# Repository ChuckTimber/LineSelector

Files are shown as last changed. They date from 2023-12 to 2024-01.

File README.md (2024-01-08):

# LineSelector

[ラインセレクタ - DIY Fx and Synthesizer](https://scrapbox.io/diyfx/%E3%83%A9%E3%82%A4%E3%83%B3%E3%82%BB%E3%83%AC%E3%82%AF%E3%82%BF)

## 仕様
- 基本仕様は A-B-Thru
- I/O は，Input / Output / SendA-ReturnA / SendB-ReturnB / TunerOut
- ２ボタン（A/B切替ボタン と Thru/FX切替ボタン）コントロール
- A/B切り替えボタンで SendA-ReturnA / SendB-ReturnB を切り替え
- Thru/FX ボタン長押しで Tunerモード（本線系はミュートしてチューナにのみ信号を流す）．Thru/FXボタンかA/Bボタンで復帰．
- なお切り替え制御はワンチップマイコン使用

## 回路図

- [version 1.0](Line_Selector_v1p0.pdf) 一部間違いあり，基板パターンを改修した上で動作実績あり
- [version 1.1](Line_Selector_v1p1.pdf) v.1.1を修正したもの．ただし基板は製作しておらず未検証

## 基板修正図

- [Patch 1.0 to 1.1](Patch_v1p0_to_v1p1.pdf) verion 1.0 の基板に対するパッチ情報（基板カットとジャンパ線）

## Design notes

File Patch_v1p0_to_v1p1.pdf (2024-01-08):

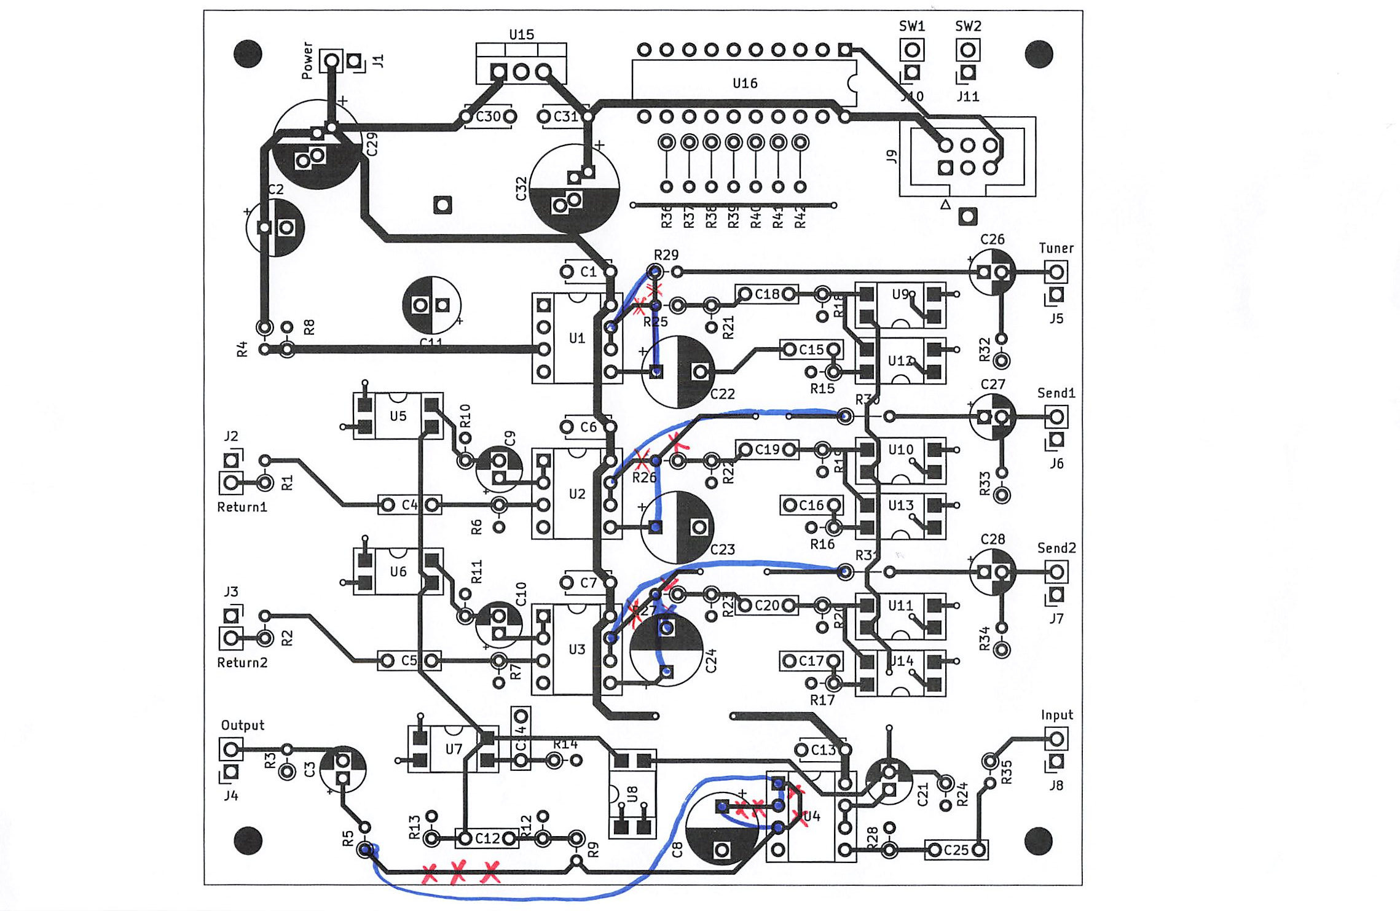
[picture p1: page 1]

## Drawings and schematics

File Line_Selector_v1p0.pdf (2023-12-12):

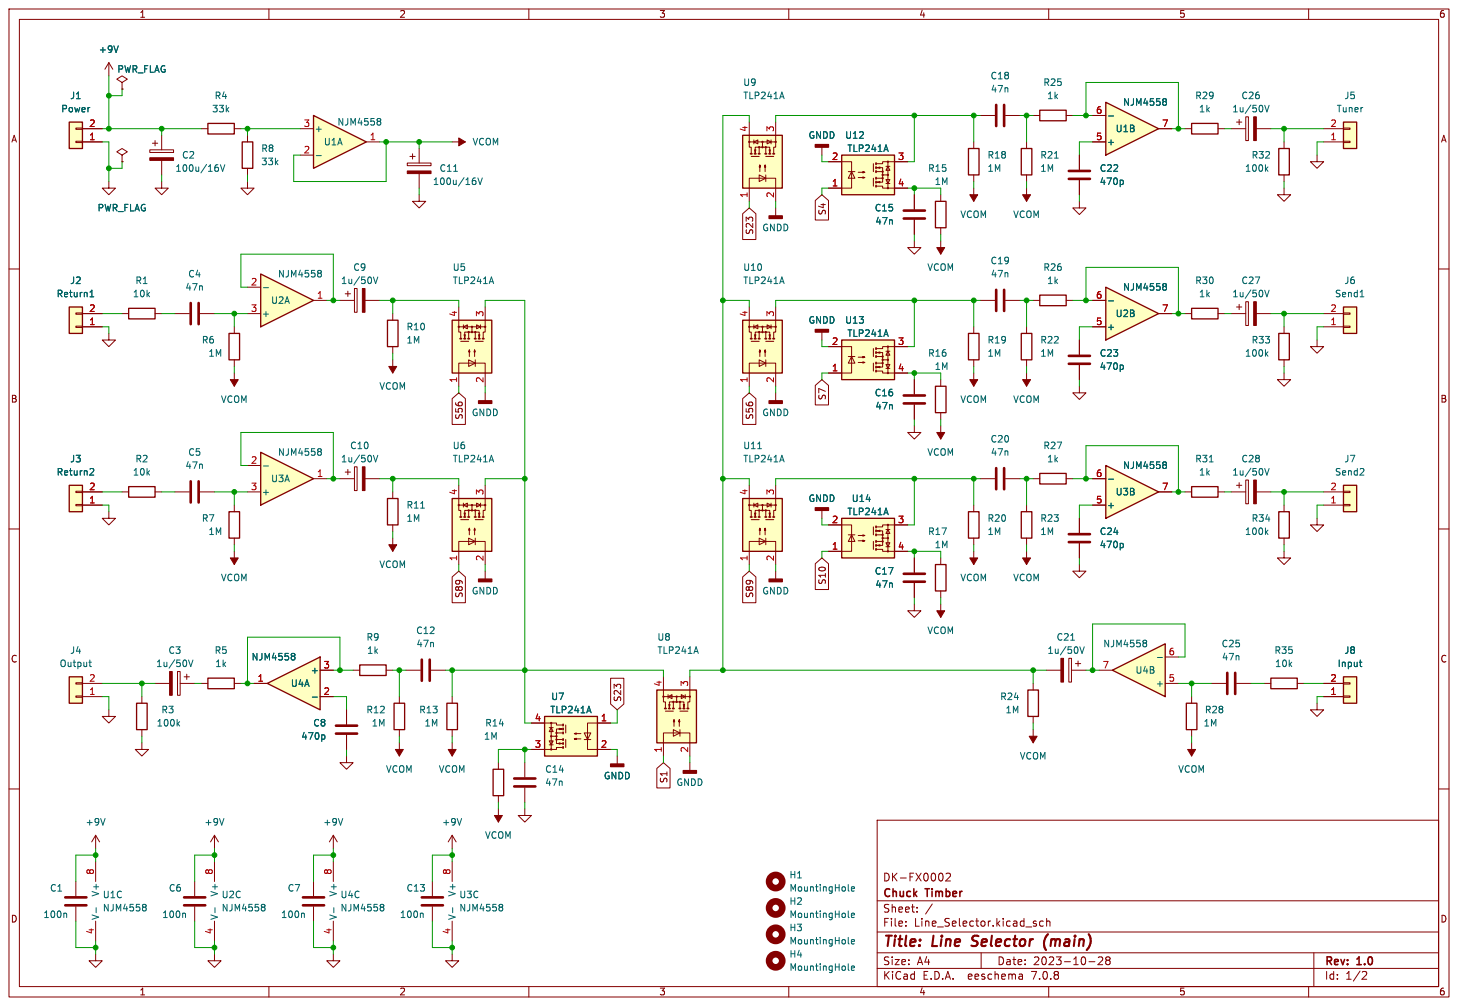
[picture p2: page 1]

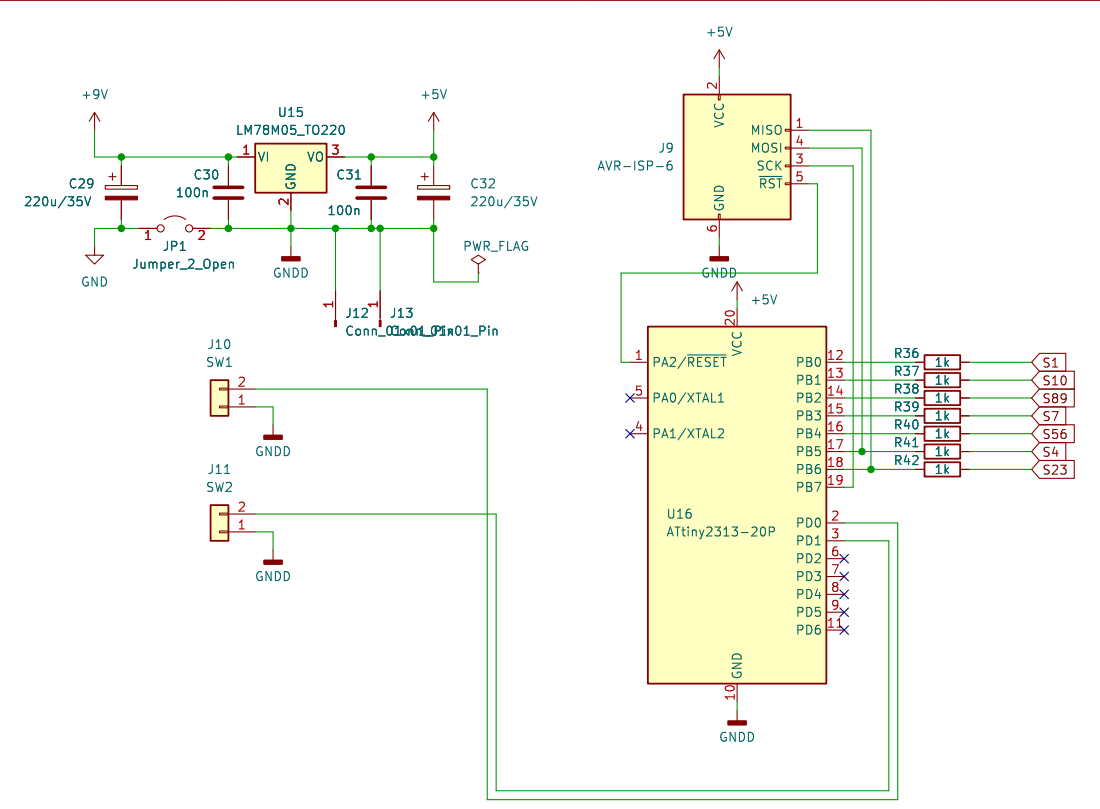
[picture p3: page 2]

2 SCK 3 MOSI 4 ~{RST}5 GND

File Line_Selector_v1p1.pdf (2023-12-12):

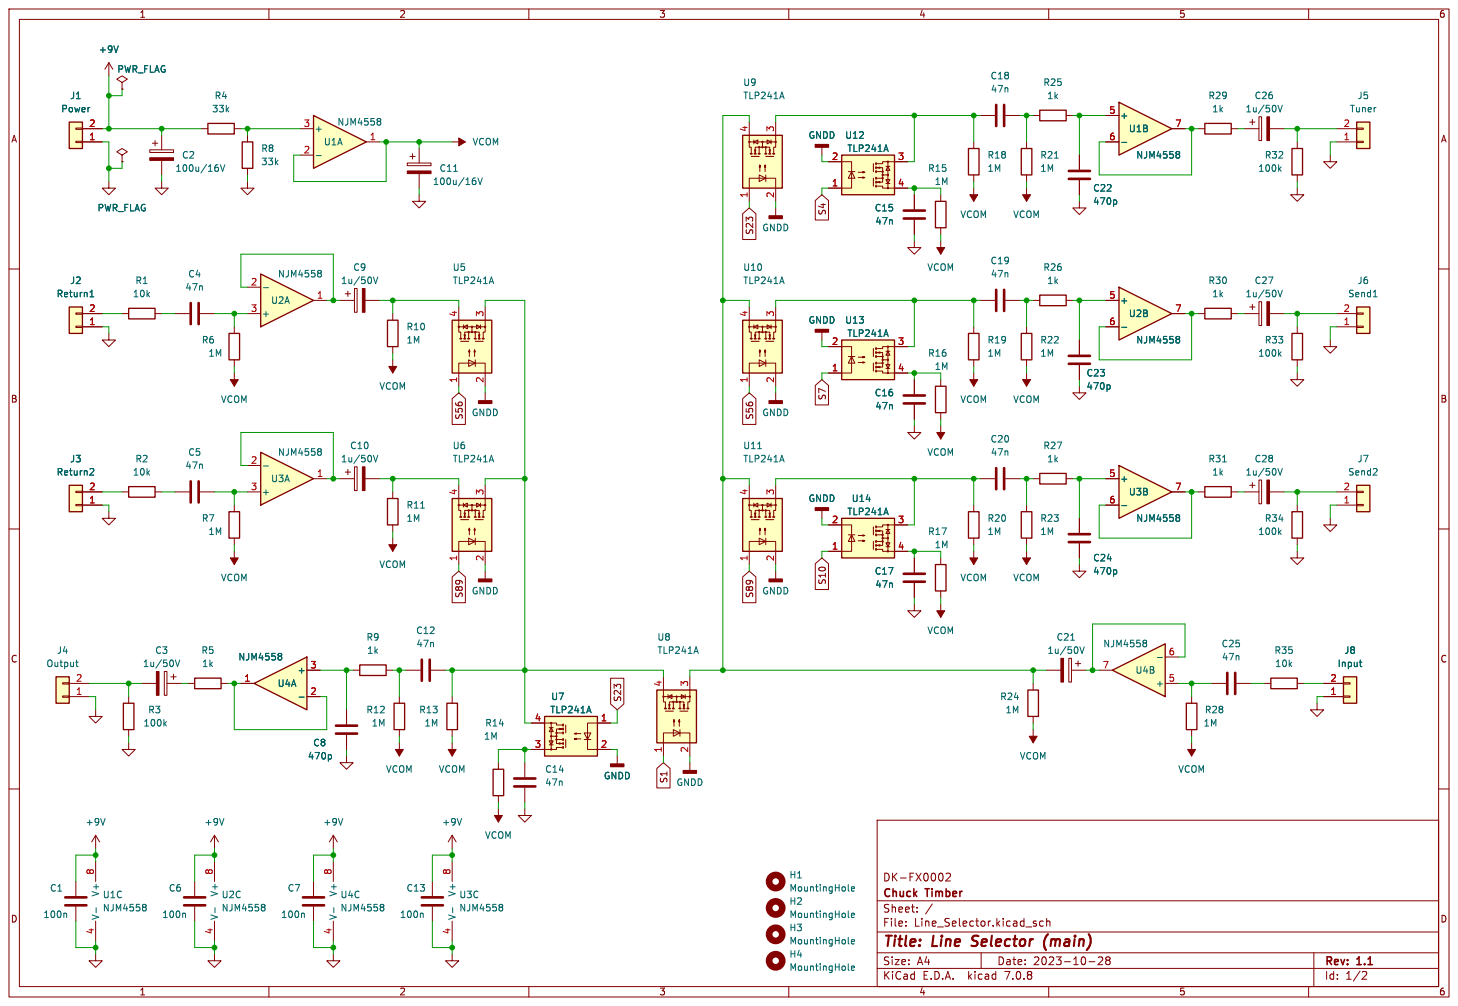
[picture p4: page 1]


2 SCK 3 MOSI 4 ~{RST}5 GND

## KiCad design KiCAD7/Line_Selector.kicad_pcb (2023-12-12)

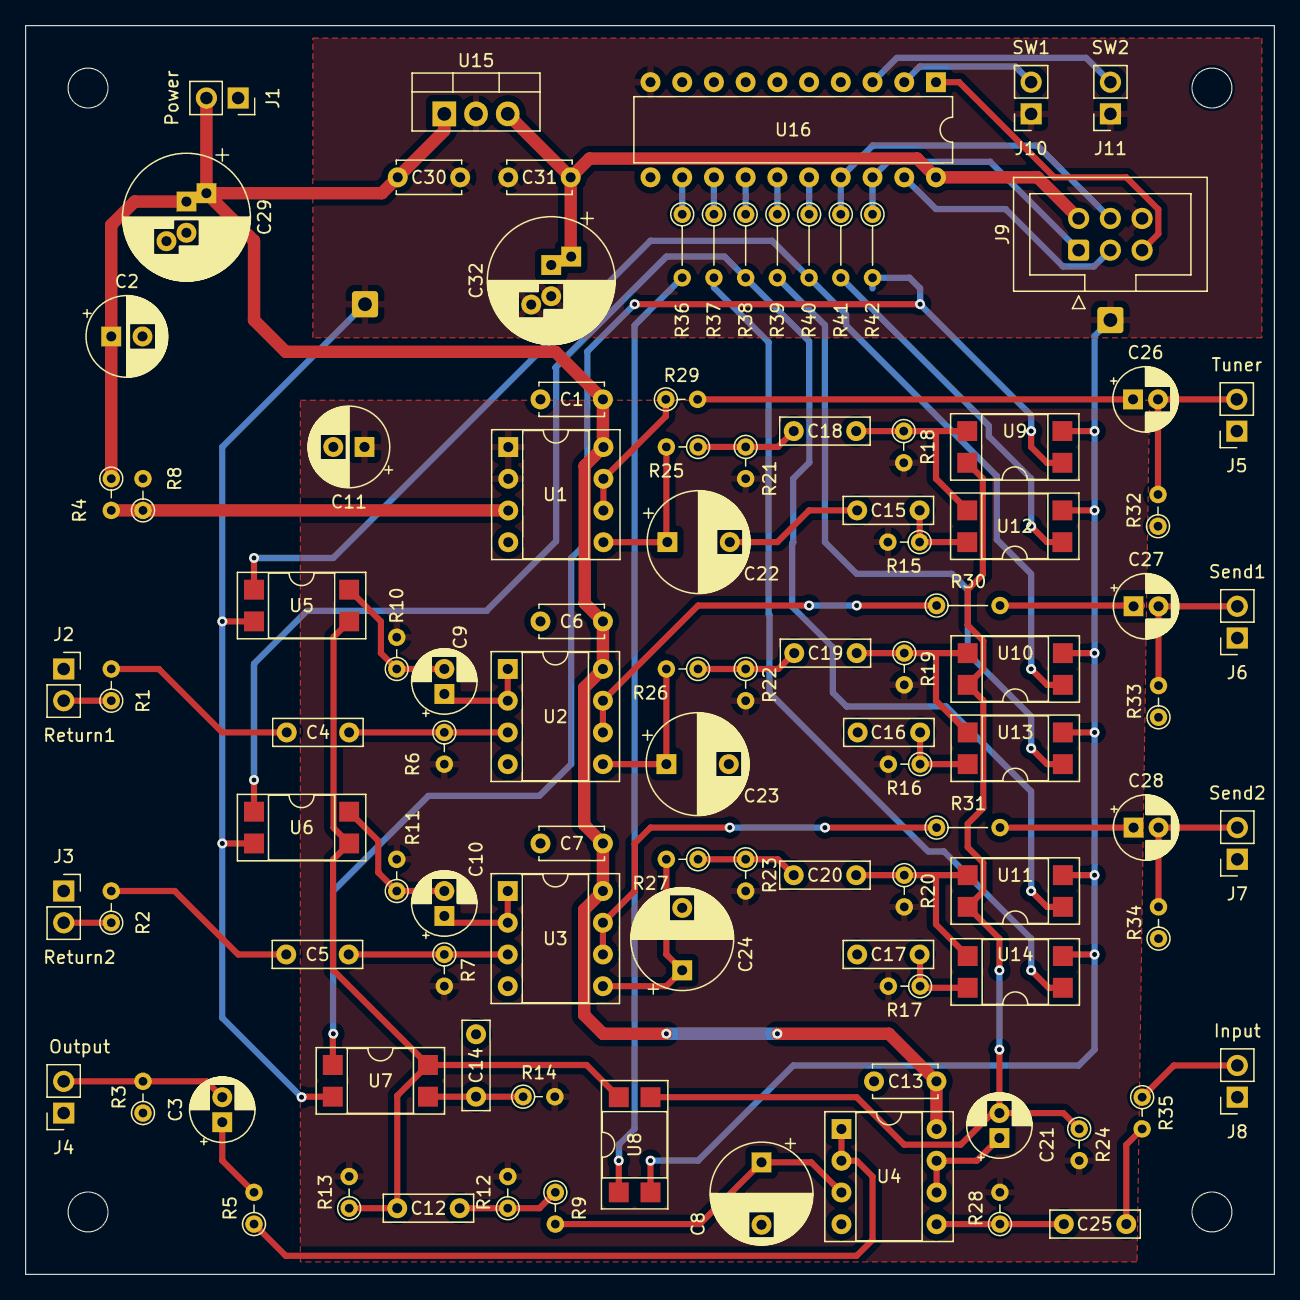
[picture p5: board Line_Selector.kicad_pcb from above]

Board: 2 copper layers, 100.0 x 100.0 mm, 107 parts (0 on the bottom side), 67 nets.

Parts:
C1, C6, C7, C13, C30, C31: 100n; C_Disc_D5.0mm_W2.5mm_P5.00mm
C2, C11: 100u/16V; CP_Radial_D6.3mm_P2.50mm
C3, C9, C10, C21, C26, C27, C28: 1u/50V; CP_Radial_D5.0mm_P2.00mm
C4, C5, C12, C14, C15, C16, C17, C18, C19, C20, C25: 47n; C_Rect_L7.0mm_W2.0mm_P5.00mm
C8, C22, C23, C24: 470p; CP_Radial_D8.0mm_P5.00mm
C29, C32: 220u/35V; CP_Radial_D10.0mm_P2.50mm_P5.00mm
H1, H2, H3, H4: MountingHole; MountingHole_3.2mm_M3
J1: Power; PinSocket_1x02_P2.54mm_Vertical
J2: Return1; PinSocket_1x02_P2.54mm_Vertical
J3: Return2; PinSocket_1x02_P2.54mm_Vertical
J4: Output; PinSocket_1x02_P2.54mm_Vertical
J5: Tuner; PinSocket_1x02_P2.54mm_Vertical
J6: Send1; PinSocket_1x02_P2.54mm_Vertical
J7: Send2; PinSocket_1x02_P2.54mm_Vertical
J8: Input; PinSocket_1x02_P2.54mm_Vertical
J9: AVR-ISP-6; IDC-Header_2x03_P2.54mm_Vertical
J10: SW1; PinSocket_1x02_P2.54mm_Vertical
J11: SW2; PinSocket_1x02_P2.54mm_Vertical
J12, J13: Conn_01x01_Pin; SolderWire-0.5sqmm_1x01_D0.9mm_OD2.1mm
R1, R2, R35: 10k; R_Axial_DIN0204_L3.6mm_D1.6mm_P2.54mm_Vertical
R3, R32, R33, R34: 100k; R_Axial_DIN0204_L3.6mm_D1.6mm_P2.54mm_Vertical
R4, R8: 33k; R_Axial_DIN0204_L3.6mm_D1.6mm_P2.54mm_Vertical
R5, R9, R25, R26, R27, R29: 1k; R_Axial_DIN0204_L3.6mm_D1.6mm_P2.54mm_Vertical
R6, R7, R10, R11, R12, R13, R14, R15, R16, R17, R18, R19, R20, R21, R22, R23, R24, R28: 1M; R_Axial_DIN0204_L3.6mm_D1.6mm_P2.54mm_Vertical
R30, R31, R36, R37, R38, R39, R40, R41, R42: 1k; R_Axial_DIN0204_L3.6mm_D1.6mm_P5.08mm_Vertical
U1, U2, U3, U4: NJM4558; DIP-8_W7.62mm_Socket
U5, U6, U7, U8, U9, U10, U11, U12, U13, U14: TLP241A; DIP-4_W7.62mm_SMDSocket_SmallPads
U15: LM78M05_TO220; TO-220-3_Vertical
U16: ATtiny2313-20P; DIP-20_W7.62mm

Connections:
+5V: C31.1, C32.1, J9.2 (VCC), U15.3 (VO), U16.20 (VCC)
+9V: C1.1, C2.1, C6.1, C7.1, C13.1, C29.1, C30.1, J1.2, R4.1, U1.8 (V+), U2.8 (V+), U3.8 (V+), U4.8 (V+), U15.1 (VI)
GND: C1.2, C2.2, C6.2, C7.2, C8.2, C11.2, C13.2, C14.2, C15.2, C16.2, C17.2, C22.2, C23.2, C24.2, C29.2, J1.1, J2.1, J3.1, J4.1, J5.1, J6.1, J7.1, J8.1, R3.1, R8.2, R32.1, R33.1, R34.1, U1.4 (V-), U2.4 (V-), U3.4 (V-), U4.4 (V-)
GNDD: C30.2, C31.2, C32.2, J9.6 (GND), J10.1, J11.1, J12.1, J13.1, U5.2, U6.2, U7.2, U8.2, U9.2, U10.2, U11.2, U12.2, U13.2, U14.2, U15.2 (GND), U16.10 (GND)
unnamed: C3.1, R5.2
unnamed: C4.1, R1.2
unnamed: C5.1, R2.2
unnamed: C9.2, R10.1, U5.4
unnamed: C10.2, R11.1, U6.4
unnamed: C12.1, R13.1, U5.3, U6.3, U7.4, U8.4
unnamed: C12.2, R9.1, R12.1
unnamed: C14.1, R14.1, U7.3
unnamed: C15.1, R15.1, U12.4
unnamed: C16.1, R16.1, U13.4
unnamed: C17.1, R17.1, U14.4
unnamed: C18.1, R18.1, U9.3, U12.3
unnamed: C18.2, R21.1, R25.1
unnamed: C19.1, R19.1, U10.3, U13.3
unnamed: C19.2, R22.1, R26.1
unnamed: C20.1, R20.1, U11.3, U14.3
unnamed: C20.2, R23.1, R27.1
unnamed: C21.2, R24.1, U8.3, U9.4, U10.4, U11.4
unnamed: C25.1, R35.2
unnamed: C26.1, R29.2
unnamed: C27.1, R30.2
unnamed: C28.1, R31.2
unnamed: J2.2, R1.1
unnamed: J3.2, R2.1
unnamed: C3.2, J4.2, R3.2
unnamed: C26.2, J5.2, R32.2
unnamed: C27.2, J6.2, R33.2
unnamed: C28.2, J7.2, R34.2
unnamed: J8.2, R35.1
unnamed: J9.1 (MISO), R42.1, U16.18 (PB6)
unnamed: J9.4 (MOSI), R41.1, U16.17 (PB5)
unnamed: J9.3 (SCK), U16.19 (PB7)
unnamed: J9.5 (~RST), U16.1 (PA2/~RESET)
unnamed: J10.2, U16.2 (PD0)
unnamed: J11.2, U16.3 (PD1)
unnamed: R4.2, R8.1, U1.3 (+)
unnamed: C22.1, R25.2, U1.5 (+)
unnamed: R29.1, U1.6 (-), U1.7
unnamed: C4.2, R6.1, U2.3 (+)
unnamed: C9.1, U2.1, U2.2 (-)
unnamed: C23.1, R26.2, U2.5 (+)
unnamed: R30.1, U2.6 (-), U2.7
unnamed: C5.2, R7.1, U3.3 (+)
unnamed: C10.1, U3.1, U3.2 (-)
unnamed: C24.1, R27.2, U3.5 (+)
unnamed: R31.1, U3.6 (-), U3.7
unnamed: C8.1, R9.2, U4.3 (+)
unnamed: R5.1, U4.1, U4.2 (-)
unnamed: C25.2, R28.1, U4.5 (+)
unnamed: C21.1, U4.6 (-), U4.7
unnamed: R36.1, U16.12 (PB0)
unnamed: R37.1, U16.13 (PB1)
unnamed: R38.1, U16.14 (PB2)
unnamed: R39.1, U16.15 (PB3)
unnamed: R40.1, U16.16 (PB4)
S1: R36.2, U8.1
S4: R41.2, U12.1
S7: R39.2, U13.1
S10: R37.2, U14.1
S23: R42.2, U7.1, U9.1
S56: R40.2, U5.1, U10.1
S89: R38.2, U6.1, U11.1
VCOM: C11.1, R6.2, R7.2, R10.2, R11.2, R12.2, R13.2, R14.2, R15.2, R16.2, R17.2, R18.2, R19.2, R20.2, R21.2, R22.2, R23.2, R24.2, R28.2, U1.1, U1.2 (-)

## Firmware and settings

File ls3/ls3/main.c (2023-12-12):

/*
 * ls3.c
 *
 * Created: 2023/11/19 18:23:57
 * Author : Chuck
 */ 

//----- Include Files ---------------------------------------------------------
#include <inttypes.h>
#include <avr/io.h>
#include <avr/interrupt.h>
#include <avr/sleep.h>
#include <stdbool.h>


// PORT definition
//		PMS		Photo MOS Switch
//		LED		Indicator LED
//		SW		Switch
#define PMS_DIR			DDRB
#define LED_DIR			DDRD
#define SW_DIR			DDRD
#define PMS_OUT			PORTB
#define SW_IN			PIND
#define SW_OUT			PORTD
#define SW_BIT_BYPASS	PD0
#define SW_BIT_AB		PD1
#define LED_BIT_BYPASS	PD5
#define LED_BIT_TUNER	PD4
#define LED_BIT_A		PD3
#define LED_BIT_B		PD2
#define LED_OUT			PORTD

#define LED_BYPASS_ON()		(LED_OUT |=   (1<<LED_BIT_BYPASS))
#define LED_BYPASS_OFF()	(LED_OUT &=  ~(1<<LED_BIT_BYPASS))
#define LED_TUNER_ON()		(LED_OUT |=   (1<<LED_BIT_TUNER))
#define LED_TUNER_OFF()		(LED_OUT &=  ~(1<<LED_BIT_TUNER))
#define LED_A_ON()			(LED_OUT |=   (1<<LED_BIT_A))
#define LED_A_OFF()			(LED_OUT &=  ~(1<<LED_BIT_A))
#define LED_B_ON()			(LED_OUT |=   (1<<LED_BIT_B))
#define LED_B_OFF()			(LED_OUT &=  ~(1<<LED_BIT_B))
#define LED_ALL_OFF()		(LED_OUT &=  ~((1<<LED_BIT_BYPASS)|(1<<LED_BIT_TUNER)|(1<<LED_BIT_A)|(1<<LED_BIT_B)))


// CODE definition
// [7:0] = 

//    mode    1  2  3  4  5  6  7  8  9  10    
//  ------------------------------------------
//   bypass   1  0  0  1  0  0  1  0  0  1     
//   tuner    0  1  1  0  0  0  1  0  0  1     
//   line1    0  0  0  1  1  1  0  0  0  1     
//   line2    0  0  0  1  0  0  1  1  1  0     

//    mode    1  23  4  56  7  89  10    ENC[7:0] = { na, S23, S4, S56, S7, S89, S10, S1 }
//  ---------------------------------------------------------------------------------------
//   bypass   1  00  1  00  1  00  1                { x 0 1 0 1 0 1 1 } = 0x2B
//   tuner    0  11  0  00  1  00  1                { x 1 0 0 1 0 1 0 } = 0x4A
//   line1    0  00  1  11  0  00  1                { x 0 1 1 0 0 1 0 } = 0x32
//   line2    0  00  1  00  1  11  0                { x 0 1 0 1 1 0 0 } = 0x2C

#define	C_BYPASS	0x2B
#define	C_TUNER		0x4A
#define	C_LINEA		0x32
#define C_LINEB		0x2C


enum { S_BYPASS, S_TUNER, S_LINE };



typedef struct key_t_tag {
	uint8_t cmd;
	uint8_t stat;
	uint8_t filt;
} key_t;

/* keyin globals */
volatile static key_t key_buf;

void key_scan(void)
{
	uint8_t a, b;

	//a = (~PIND & 0x0F);
	a = (~SW_IN & ((1<<SW_BIT_AB)|(1<<SW_BIT_BYPASS)));
	if (a == key_buf.filt) {
		b = key_buf.stat;
		key_buf.stat = a;
		b = (b ^ a) & a;
		if (b) {
			key_buf.cmd = b;
		}
	}
	key_buf.filt = a;

}


enum { na = 0, btn_BYPASS, btn_LINE, btn_BYPASS_LONG };
static volatile int cmd;

void cmd_check(void)
{
	static unsigned long int check_long = 0;

	cmd = na;
 
#if 0

	if ( key_buf.stat & (1<<SW_BIT_BYPASS) ) {
		if ( check_long == 0)	check_long = 1;
		else check_long++;
	} else {
		if ( check_long ) check_long = 0;
	}

	if ( check_long > 96 ) {
		cmd = btn_BYPASS_LONG;
	} else if ( key_buf.cmd & (1<<SW_BIT_AB)) {
		cmd = btn_LINE;
		key_buf.cmd = 0;
	} else if ( key_buf.cmd & (1<<SW_BIT_BYPASS)) {
		cmd = btn_BYPASS;
		key_buf.cmd = 0;
	}

#else

	if ( key_buf.stat & (1<<SW_BIT_BYPASS) ) {
		if ( check_long == 0)	check_long = 1;
		else check_long++;
		if ( check_long > 96 ) {
			cmd = btn_BYPASS_LONG;
			key_buf.cmd = 0;
		}
	} else {
		if ( check_long ) check_long = 0;
		if ( key_buf.cmd & (1<<SW_BIT_AB)) {
			cmd = btn_LINE;
			key_buf.cmd = 0;
		} else if ( key_buf.cmd & (1<<SW_BIT_BYPASS)) {
			cmd = btn_BYPASS;
			key_buf.cmd = 0;
		}
	}

#endif

}

/*
 * Int every 2msec on 1MHz system clock
 */
ISR(TIMER0_OVF_vect)
{
	static uint8_t process;

	++process;
	// process 1 of 16 times
	if ((process & 0x0F)==0x01)	key_scan();
	if ((process & 0x0F)==0x02)	cmd_check();
	

}

void timer0Init(void)
{
	// start timer0
	TCNT0 = 0;
	TCCR0B |= (1<<CS01)|(0<<CS00);		// set prescaler by 8 1MHz/256/8 -> 2msec
	TIMSK |= (1<<TOIE0);

	sei();
}

void ioInit(void)
{
	PMS_DIR |= 0x7F;	// for Photo MOS Switch control (output)
	SW_OUT |= (1<<SW_BIT_AB);
	SW_OUT |= (1<<SW_BIT_BYPASS);
	SW_DIR &= ~(1<<SW_BIT_AB);
	SW_DIR &= ~(1<<SW_BIT_BYPASS);
	LED_DIR |= (1<<LED_BIT_BYPASS);
	LED_DIR |= (1<<LED_BIT_TUNER);
	LED_DIR |= (1<<LED_BIT_A);
	LED_DIR |= (1<<LED_BIT_B);
}

enum { LINEA = 0, LINEB = 1 };
void port_output(int state, bool tgl)
{
	static int store_LINE = LINEA;
	
	switch ( state ) {
	case S_BYPASS:
		PMS_OUT = C_BYPASS;
		LED_ALL_OFF();
		LED_BYPASS_ON();
		break;
	case S_TUNER:
		PMS_OUT = C_TUNER;
		LED_ALL_OFF();
		LED_TUNER_ON();
		break;
	case S_LINE:
		if (tgl) {
			if( store_LINE == LINEA) {
				PMS_OUT = C_LINEB;
				store_LINE = LINEB;
				LED_ALL_OFF();
				LED_B_ON();
			} else {
				PMS_OUT = C_LINEA;
				store_LINE = LINEA;
				LED_ALL_OFF();
				LED_A_ON();
			}
		} else {
			if( store_LINE == LINEA) {
				PMS_OUT = C_LINEA;
				LED_ALL_OFF();
				LED_A_ON();
			} else {
				PMS_OUT = C_LINEB;
				LED_ALL_OFF();
				LED_B_ON();
			}
		}
		break;
	}
}


int main(void)
{
	int state = S_BYPASS;
	bool tgl = false;
	
	ioInit();
	timer0Init();

	port_output(state, false);
	
    /* Replace with your application code */
    while (1) {
		sleep_cpu();
		
		if (cmd) {
			switch ( state ) {
			case S_BYPASS:
				switch ( cmd ) {
				case btn_BYPASS:
				case btn_LINE:
					state = S_LINE;
					tgl = false;
					break;
				case btn_BYPASS_LONG:
					state = S_TUNER;
					break;
				}
				cmd = na;
				break;
			case S_TUNER:
				switch ( cmd ) {
				case btn_BYPASS:
					state = S_BYPASS;
					break;
				case btn_LINE:
					state = S_LINE;
					tgl = false;
					break;
				}
				cmd = na;
				break;
			case S_LINE:
				switch ( cmd ) {
				case btn_BYPASS:
					state = S_BYPASS;
					break;		
				case btn_LINE:
					state = S_LINE;
					tgl = true;
					break;
				case btn_BYPASS_LONG:
					state = S_TUNER;
					break;
				}
				cmd = na;
				break;
			}
			port_output(state, tgl);
		}



    }
}

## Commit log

2023-12-12 Add schematic PDF
2023-12-12 Added KiCAD portion
    [Line_Selector.kicad_pcb, Line_Selector.kicad_sch, control.kicad_sch]
2024-01-08 Added the pcb patch information
